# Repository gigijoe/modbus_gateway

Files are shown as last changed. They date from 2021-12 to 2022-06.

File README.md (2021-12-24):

## ESP32 Modbus TCP / RTU / ASCII Gateway

#### Hardware
ESP32 TTGO T8V1.7 16MB FLASH / 8MB PSRAM

Hardware

#### Feature
1.Combine Modbus TCP slave and Modbus RTU / ASCII master to act as Modbus TCP / RTU / ASCII Gateway\
2.Supports maximum 8 Modbus TCP connections synchronously. Listen on port 503\
3.Supports Modbus TCP slave of 8 digital input and 8 digital output locally. Listen on port 502\
4.Supports Wifi Access Point / Station / Ethernet network\
5.Supports mDNS service for zero IP configuration\
6.Supports DS1307 hardware RTC\
7.Supports NTP client\
8.Supports 1 port DS18B20 temperature sensor\
9.Supports 1 port ADC voltage reading\
10.Supports 20 x 4 dot matric LCD\

#### Reference

https://github.com/maxx-ukoo/esp32-modbus-tcp2rtu

https://github.com/iot-lorawan/esp32-ota-ble

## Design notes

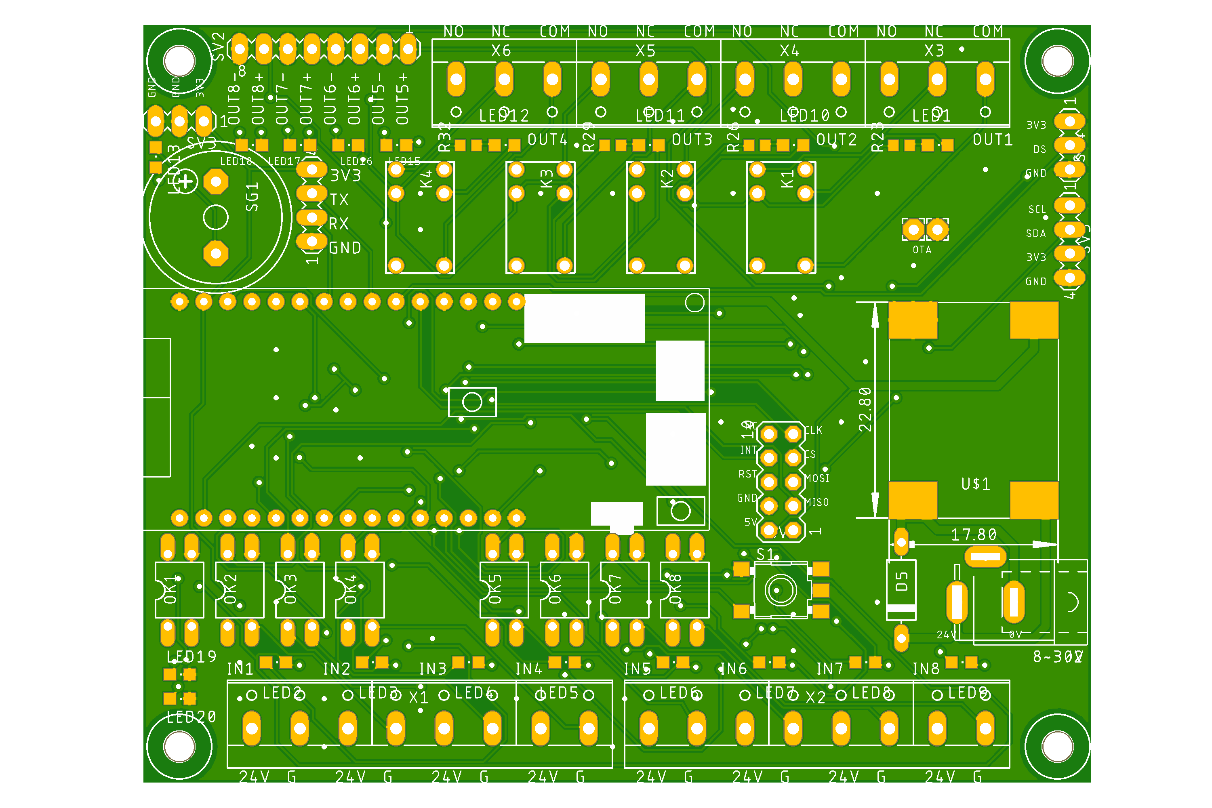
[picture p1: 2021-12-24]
hardware/7.x/top.png

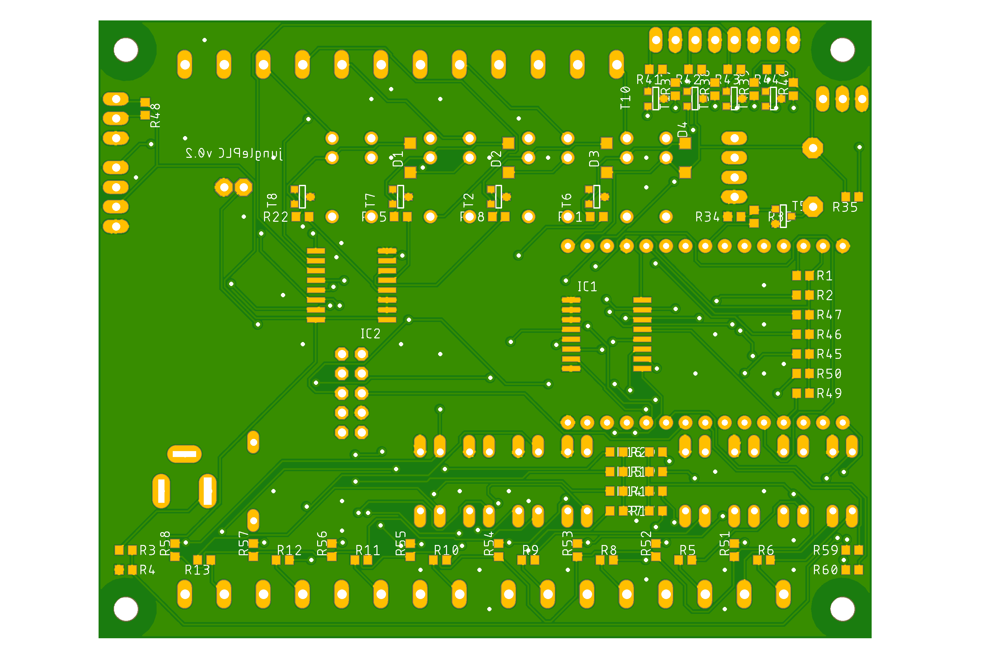
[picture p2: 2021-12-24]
hardware/7.x/bottom.png

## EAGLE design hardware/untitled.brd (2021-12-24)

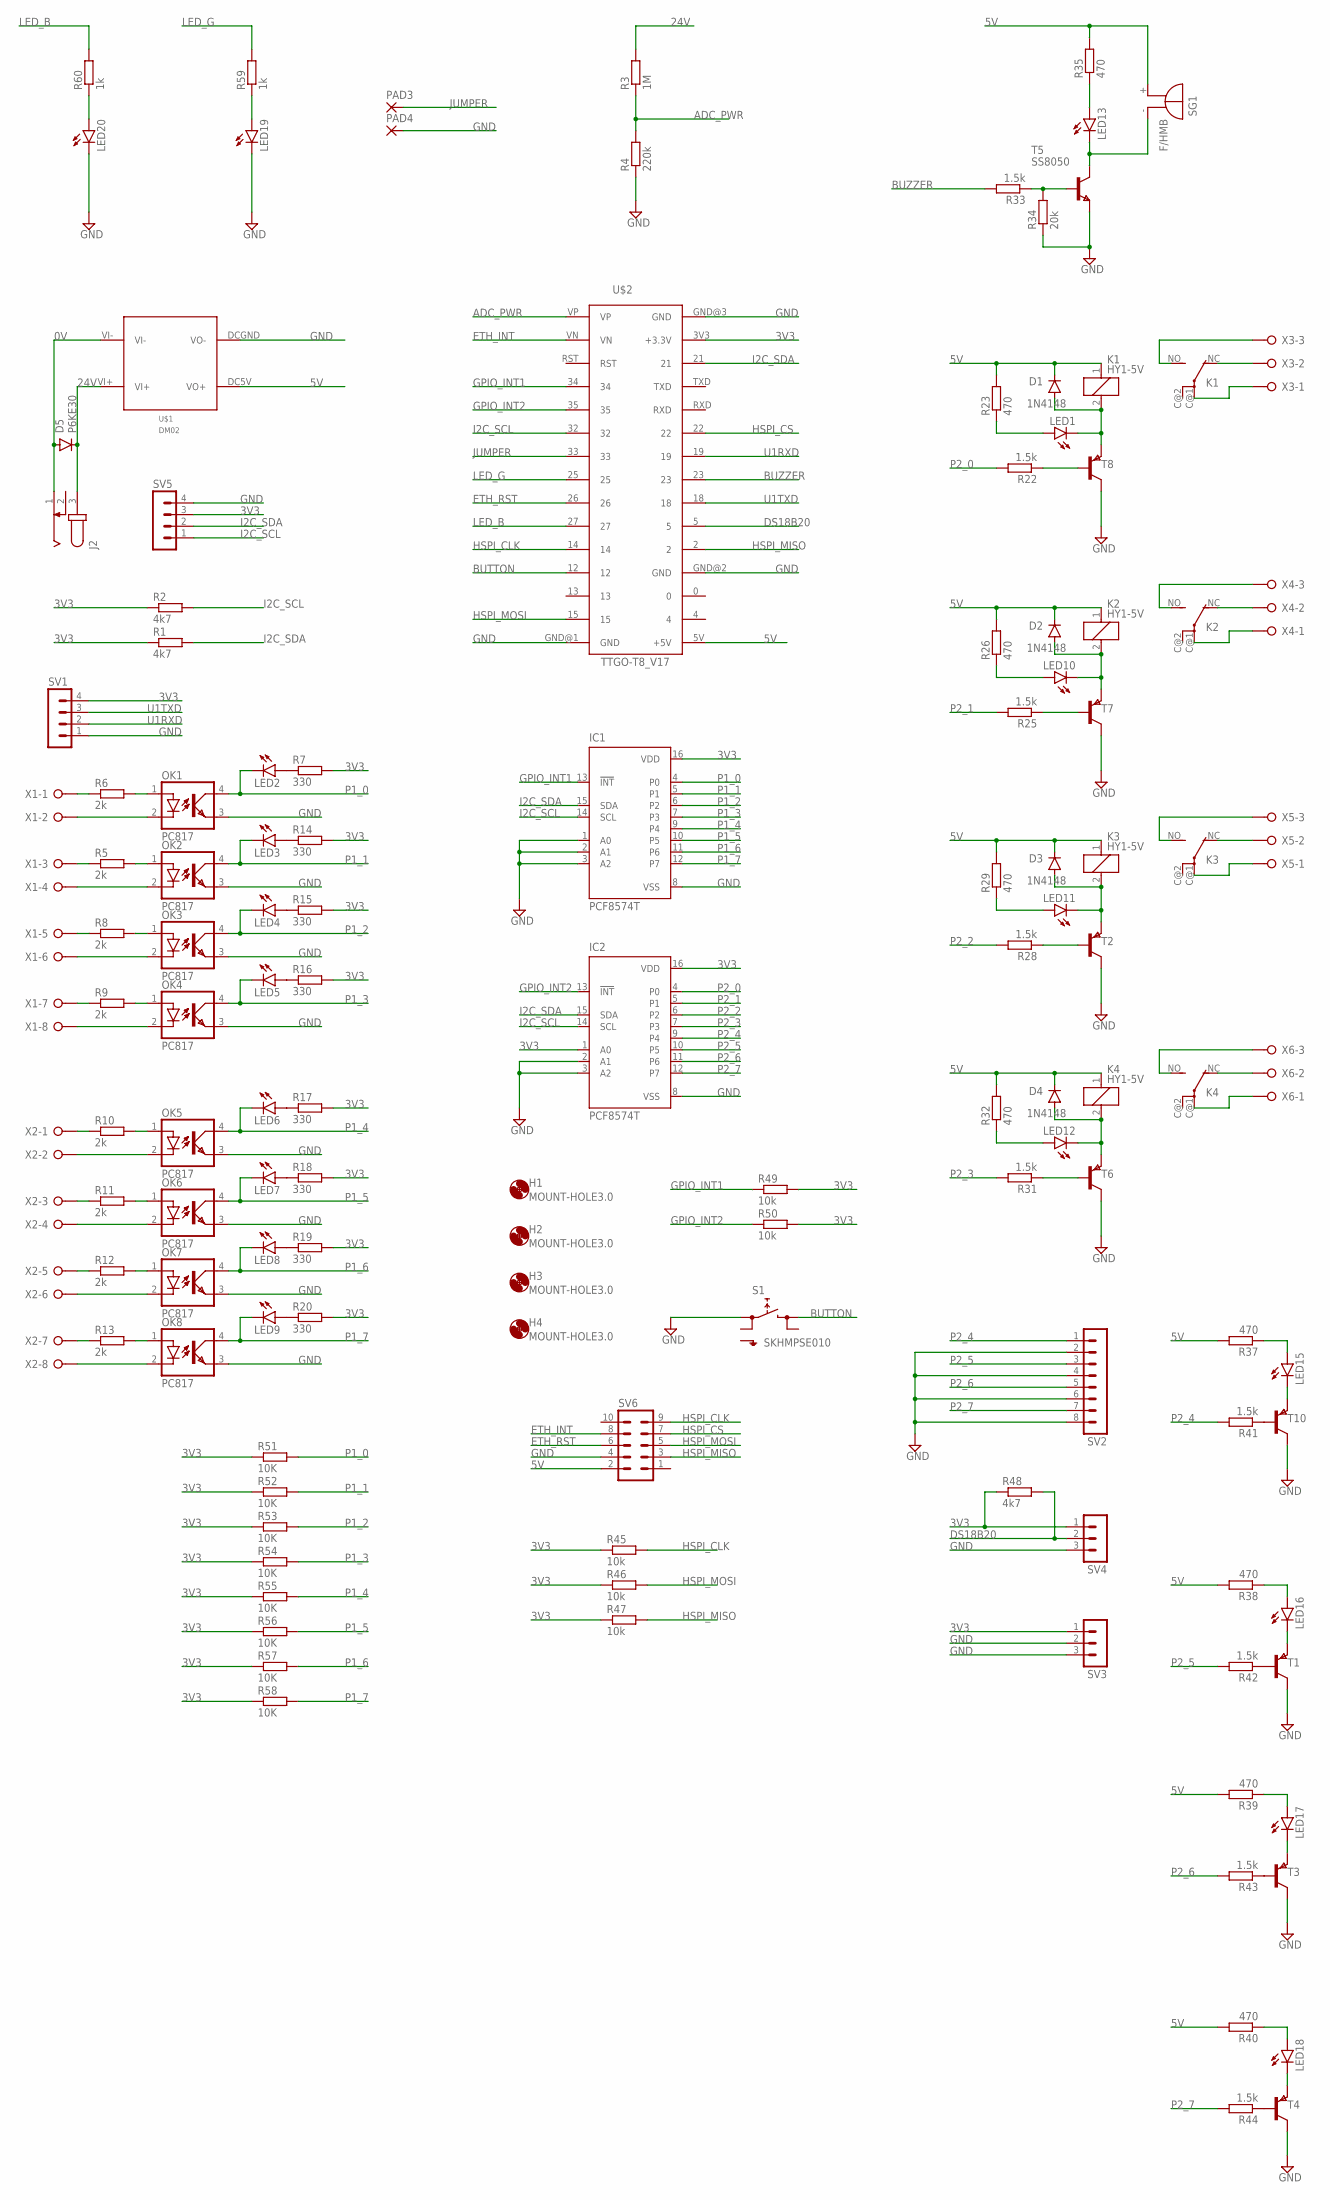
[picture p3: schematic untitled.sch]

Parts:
D1, D2, D3, D4: 1N4148; SOD123
D5: P6KE30; D-10
H1, H2, H3, H4: MOUNT-HOLE3.0; 3,0
IC1, IC2: PCF8574T; SO16W
J2: JACK-PLUG0; SPC4077
K1, K2, K3, K4: HY1-5V; HY
LED1, LED2, LED3, LED4, LED5, LED6, LED7, LED8, LED9, LED10, LED11, LED12, LED13, LED15, LED16, LED17, LED18, LED19, LED20: LEDCHIPLED_0805; CHIPLED_0805
OK1, OK2, OK3, OK4, OK5, OK6, OK7, OK8: PC817; DIL04
PAD3, PAD4: 2,15/1,0
R1, R2, R48: 4k7; R0603
R3: 1M; R0603
R4: 220k; R0603
R5, R6, R8, R9, R10, R11, R12, R13: 2k; R0603
R7, R14, R15, R16, R17, R18, R19, R20: 330; R0603
R22, R25, R28, R31, R33, R41, R42, R43, R44: 1.5k; R0603
R23, R26, R29, R32, R35, R37, R38, R39, R40: 470; R0603
R34: 20k; R0603
R45, R46, R47, R49, R50: 10k; R0603
R51, R52, R53, R54, R55, R56, R57, R58: 10K; R0603
R59, R60: 1k; R0603
S1: SKHMPSE010; SKHMPXE010
SG1: F/HMB
SV1, SV5: MA04-1
SV2: MA08-1
SV3, SV4: MA03-1
SV6: MA05-2
T1, T2, T3, T4, T6, T7, T8, T10: PNPSOT23; SOT-23
T5: SS8050; SOT-23
U$1: DM02
U$2: TTGO-T8_V17
X1, X2: W237-08P; W237-8P
X3, X4, X5, X6: W237-03P; W237-133

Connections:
0V: D5.A, J2.1, U$1.VI-
3V3: IC1.16 (VDD), IC2.1 (A0), IC2.16 (VDD), R1.1, R2.1, R7.2, R14.2, R15.2, R16.2, R17.2, R18.2, R19.2, R20.2, R45.1, R46.1, R47.1, R48.1, R49.2, R50.2, R51.1, R52.1, R53.1, R54.1, R55.1, R56.1, R57.1, R58.1, SV1.4, SV3.1, SV4.1, SV5.3, U$2.3V3 (+3.3V)
5V: D1.C, D2.C, D3.C, D4.C, K1.1, K2.1, K3.1, K4.1, R23.2, R26.2, R29.2, R32.2, R35.2, R37.2, R38.2, R39.2, R40.2, SG1.+, SV6.2, U$1.DC5V (VO+), U$2.5V (+5V)
24V: D5.C, J2.3, R3.2, U$1.VI+
ADC_PWR: R3.1, R4.2, U$2.VP
BUTTON: S1.3 (2.1), U$2.12
BUZZER: R33.2, U$2.23
DS18B20: R48.2, SV4.2, U$2.5
ETH_INT: SV6.8, U$2.VN
ETH_RST: SV6.6, U$2.26
GND: IC1.1 (A0), IC1.2 (A1), IC1.3 (A2), IC1.8 (VSS), IC2.2 (A1), IC2.3 (A2), IC2.8 (VSS), LED19.C, LED20.C, OK1.3 (EMIT), OK2.3 (EMIT), OK3.3 (EMIT), OK4.3 (EMIT), OK5.3 (EMIT), OK6.3 (EMIT), OK7.3 (EMIT), OK8.3 (EMIT), PAD4.1, R4.1, R34.1, S1.1 (1.1), SV1.1, SV2.2, SV2.4, SV2.6, SV2.8, SV3.2, SV3.3, SV4.3, SV5.4, SV6.4, T1.1 (C), T2.1 (C), T3.1 (C), T4.1 (C), T5.2 (E), T6.1 (C), T7.1 (C), T8.1 (C), T10.1 (C), U$1.DCGND (VO-), U$2.GND@1 (GND), U$2.GND@2 (GND), U$2.GND@3 (GND)
GPIO_INT1: IC1.13 (!INT), R49.1, U$2.34
GPIO_INT2: IC2.13 (!INT), R50.1, U$2.35
HSPI_CLK: R45.2, SV6.9, U$2.14
HSPI_CS: SV6.7, U$2.22
HSPI_MISO: R47.2, SV6.3, U$2.2
HSPI_MOSI: R46.2, SV6.5, U$2.15
I2C_SCL: IC1.14 (SCL), IC2.14 (SCL), R2.2, SV5.1, U$2.32
I2C_SDA: IC1.15 (SDA), IC2.15 (SDA), R1.2, SV5.2, U$2.21
JUMPER: PAD3.1, U$2.33
LED_B: R60.2, U$2.27
LED_G: R59.2, U$2.25
unnamed: R5.1, X1.3
unnamed: R6.1, X1.1
unnamed: OK1.1 (A), R6.2
unnamed: OK1.2 (C), X1.2
unnamed: OK2.1 (A), R5.2
unnamed: OK2.2 (C), X1.4
unnamed: R8.1, X1.5
unnamed: OK3.1 (A), R8.2
unnamed: OK3.2 (C), X1.6
unnamed: R9.1, X1.7
unnamed: OK4.1 (A), R9.2
unnamed: OK4.2 (C), X1.8
unnamed: R10.1, X2.1
unnamed: OK5.1 (A), R10.2
unnamed: OK5.2 (C), X2.2
unnamed: R11.1, X2.3
unnamed: OK6.1 (A), R11.2
unnamed: OK6.2 (C), X2.4
unnamed: R12.1, X2.5
unnamed: OK7.1 (A), R12.2
unnamed: OK7.2 (C), X2.6
unnamed: R13.1, X2.7
unnamed: OK8.1 (A), R13.2
unnamed: OK8.2 (C), X2.8
unnamed: R25.1, T7.3 (B)
unnamed: LED1.A, R23.1
unnamed: D2.A, K2.2, LED10.C, T7.2 (E)
unnamed: LED2.A, R7.1
unnamed: LED3.A, R14.1
unnamed: LED4.A, R15.1
unnamed: LED15.A, R37.1
unnamed: LED16.C, T1.2 (E)
unnamed: LED5.A, R16.1
unnamed: LED19.A, R59.1
unnamed: R22.1, T8.3 (B)
unnamed: D1.A, K1.2, LED1.C, T8.2 (E)
unnamed: K1.NO (S), X3.3
unnamed: K1.NC (O), X3.2
unnamed: R28.1, T2.3 (B)
unnamed: D3.A, K3.2, LED11.C, T2.2 (E)
unnamed: LED10.A, R26.1
unnamed: LED11.A, R29.1
unnamed: R31.1, T6.3 (B)
unnamed: D4.A, K4.2, LED12.C, T6.2 (E)
unnamed: LED12.A, R32.1
unnamed: K1.C@1, X3.1
unnamed: K2.NO (S), X4.3
unnamed: K2.NC (O), X4.2
unnamed: K2.C@1, X4.1
unnamed: K3.NO (S), X5.3
unnamed: K3.NC (O), X5.2
unnamed: K3.C@1, X5.1
unnamed: K4.NO (S), X6.3
unnamed: K4.NC (O), X6.2
unnamed: K4.C@1, X6.1
unnamed: LED15.C, T10.2 (E)
unnamed: LED20.A, R60.1
unnamed: R33.1, R34.2, T5.3 (B)
unnamed: R41.1, T10.3 (B)
unnamed: LED13.A, R35.1
unnamed: LED13.C, SG1.-, T5.1 (C)
unnamed: LED9.A, R20.1
unnamed: LED16.A, R38.1
unnamed: LED17.C, T3.2 (E)
unnamed: LED17.A, R39.1
unnamed: LED18.C, T4.2 (E)
unnamed: LED18.A, R40.1
unnamed: R42.1, T1.3 (B)
unnamed: R43.1, T3.3 (B)
unnamed: R44.1, T4.3 (B)
unnamed: LED8.A, R19.1
unnamed: LED7.A, R18.1
unnamed: LED6.A, R17.1
P1_0: IC1.4 (P0), LED2.C, OK1.4 (COL), R51.2
P1_1: IC1.5 (P1), LED3.C, OK2.4 (COL), R52.2
P1_2: IC1.6 (P2), LED4.C, OK3.4 (COL), R53.2
P1_3: IC1.7 (P3), LED5.C, OK4.4 (COL), R54.2
P1_4: IC1.9 (P4), LED6.C, OK5.4 (COL), R55.2
P1_5: IC1.10 (P5), LED7.C, OK6.4 (COL), R56.2
P1_6: IC1.11 (P6), LED8.C, OK7.4 (COL), R57.2
P1_7: IC1.12 (P7), LED9.C, OK8.4 (COL), R58.2
P2_0: IC2.4 (P0), R22.2
P2_1: IC2.5 (P1), R25.2
P2_2: IC2.6 (P2), R28.2
P2_3: IC2.7 (P3), R31.2
P2_4: IC2.9 (P4), R41.2, SV2.1
P2_5: IC2.10 (P5), R42.2, SV2.3
P2_6: IC2.11 (P6), R43.2, SV2.5
P2_7: IC2.12 (P7), R44.2, SV2.7
U1RXD: SV1.2, U$2.19
U1TXD: SV1.3, U$2.18

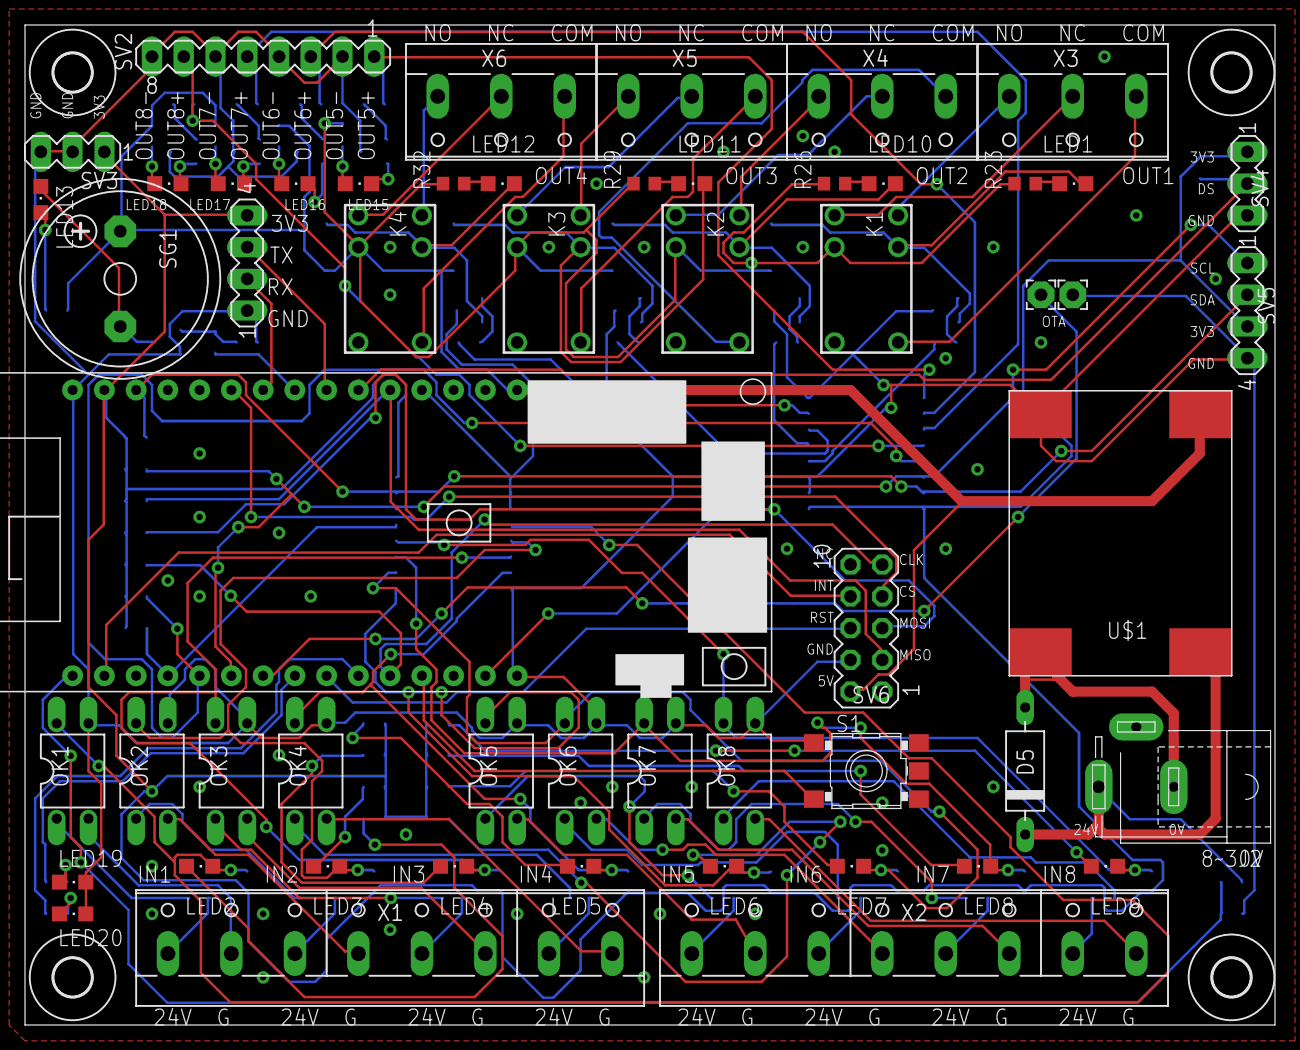
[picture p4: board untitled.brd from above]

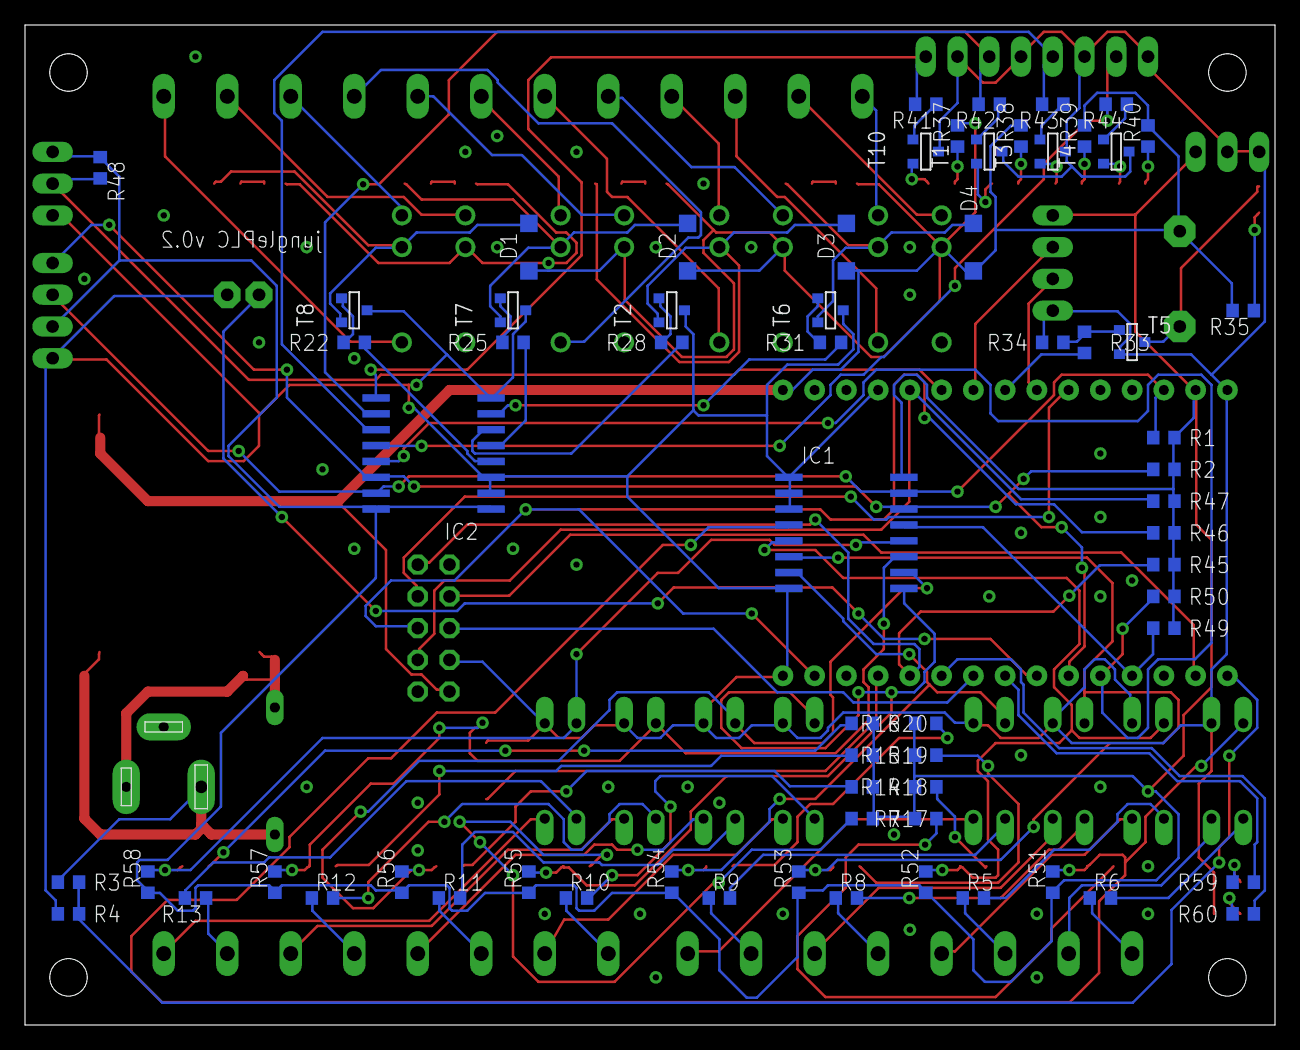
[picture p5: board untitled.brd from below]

Board: 2 copper layers, 100.0 x 80.0 mm, 125 parts (66 on the bottom side), 113 nets.

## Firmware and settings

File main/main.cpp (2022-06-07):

/* FreeModbus Slave Example ESP32

   Unless required by applicable law or agreed to in writing, this
   software is distributed on an "AS IS" BASIS, WITHOUT WARRANTIES OR
   CONDITIONS OF ANY KIND, either express or implied.
*/
#include <stdio.h>
#include "esp_err.h"
#include "sdkconfig.h"
#include "esp_log.h"
#include "esp_check.h"
#include "esp_system.h"
#include "esp_wifi.h"
#include "esp_event.h"
#include "esp_sntp.h"
#include "esp_mac.h"
#include "esp_chip_info.h"
#include "nvs_flash.h"

#include "mdns.h"
#include "esp_netif.h"

#include "driver/gpio.h"
#include "esp32/rom/gpio.h"
#include "driver/i2c.h"
#include "soc/rtc_io_reg.h"

#include "driver/adc.h"
#include "esp_adc_cal.h"

#include "network.h"
#include "telnetd.h"
#include "icmp_echo.h"

#include "esp_vfs.h"
#include "esp_vfs_dev.h"
#include "esp_console.h"
#include "driver/uart.h"
#include "linenoise/linenoise.h"
#include "argtable3/argtable3.h"

#include "led.h"
#include "i2cdev.h"
#include "ds1307.h"
#include "ds3231.h"
#include "ds18b20.h"
#include "pcf8574.hpp"
#include "lcd204-i2c.hpp"
//#include "sdmmc.h"

#include "modbus_tcp_slave.h"
#include "modbus_tcp2serial.h"
#include "modbus_data.h"

#include <lwip/dns.h>

#include <lwip/err.h>
#include <lwip/sockets.h>
#include <lwip/sys.h>
#include <lwip/netdb.h>
#include <lwip/err.h>

#include "ota_ble.h"
#include "ota_https.h"

#include "http_server.h"

#define TAG "Main"

static nvs_handle my_nvs_handle;

#define HOSTNAME_MAX_LEN 32
#define DESCRIPTION_MAX_LEN 64

typedef struct {
    char hostname[HOSTNAME_MAX_LEN];
    char description[DESCRIPTION_MAX_LEN];
#if CONFIG_EXAMPLE_CONNECT_ETHERNET
    bool enable_eth;
#endif
    bool enable_ntp;
    bool enable_mdns;
    bool enable_telnetd;
    bool enable_modbus_tcp2serial;
} sys_cfg_t;

static sys_cfg_t s_sys_cfg = {}; 

// https://blog.csdn.net/libin55/article/details/108206159

#define SYSLOG_QUEUE_SIZE   4096
#define SIZEOF_SYSLOG       sizeof(syslog_t)

/* The variable used to hold the queue's data structure. */
static StaticQueue_t xStaticQueue;
//EXT_RAM_ATTR uint8_t ucQueueStorageArea[ SYSLOG_QUEUE_SIZE * SIZEOF_SYSLOG ];
EXT_RAM_BSS_ATTR uint8_t ucQueueStorageArea[ SYSLOG_QUEUE_SIZE * SIZEOF_SYSLOG ];

static QueueHandle_t s_syslog_queue;

#define CMD_SYS_CFG  "sys_cfg"

void system_load_config()
{
    esp_err_t err = nvs_open("storage", NVS_READWRITE, &my_nvs_handle);
    if(err != ESP_OK) {
        ESP_LOGE(TAG, "Error (%d) opening NVS!\n", err);
        return;
    }

    size_t l = sizeof(sys_cfg_t);
    err = nvs_get_blob(my_nvs_handle, CMD_SYS_CFG, &s_sys_cfg, &l);
    if(err != ESP_OK) {
        ESP_LOGI(TAG, "No system config cached ...");
    }    

    nvs_close(my_nvs_handle);
}

void system_save_config()
{
    esp_err_t err = nvs_open("storage", NVS_READWRITE, &my_nvs_handle);
    if(err != ESP_OK) {
        ESP_LOGE(TAG, "Error (%d) opening NVS!\n", err);
        return;
    }

    err = nvs_set_blob(my_nvs_handle, CMD_SYS_CFG, &s_sys_cfg, sizeof(s_sys_cfg));
    if(err != ESP_OK)
        ESP_LOGE(TAG, "Fail save system config !!!");

    nvs_commit(my_nvs_handle);
    nvs_close(my_nvs_handle);
}

void system_factory_reset()
{
    esp_err_t err = nvs_open("storage", NVS_READWRITE, &my_nvs_handle);

    if(err != ESP_OK) {
        ESP_LOGE(TAG, "Error (%d) opening NVS!\n", err);
        return;
    }

    nvs_erase_key(my_nvs_handle, CMD_SYS_CFG);

    nvs_commit(my_nvs_handle);
    nvs_close(my_nvs_handle);
}

/*
*
*/

#if CONFIG_MB_MDNS_IP_RESOLVER

#define MB_MDNS_PORT            (CONFIG_FMB_TCP_PORT_DEFAULT)

#if CONFIG_FMB_CONTROLLER_SLAVE_ID_SUPPORT
#define MB_DEVICE_ID (uint32_t)CONFIG_FMB_CONTROLLER_SLAVE_ID
#endif

// convert mac from binary format to string
static inline char* gen_mac_str(const uint8_t* mac, const char* pref, char* mac_str)
{
    sprintf(mac_str, "%s%02X%02X%02X%02X%02X%02X", pref, MAC2STR(mac));
    return mac_str;
}

static void start_mdns_service(void)
{
    char temp_str[32] = {0};
    uint8_t sta_mac[6] = {0};
    ESP_ERROR_CHECK(esp_read_mac(sta_mac, ESP_MAC_WIFI_STA));
    const char *hostname = s_sys_cfg.hostname;
    //initialize mDNS
    ESP_ERROR_CHECK(mdns_init());
    //set mDNS hostname (required if you want to advertise services)
    ESP_ERROR_CHECK(mdns_hostname_set(hostname));
    ESP_LOGI(TAG, "mdns hostname set to: [%s]", hostname);

    //set default mDNS instance name
    ESP_ERROR_CHECK(mdns_instance_name_set(hostname));

    //structure with TXT records
    mdns_txt_item_t serviceTxtData[] = {
        {"board","modbus_gateway"} // board=modbus_gateway
    };

    //initialize service
    ESP_ERROR_CHECK(mdns_service_add(hostname, "_modbus", "_tcp", MB_MDNS_PORT, serviceTxtData, 1));
    //add mac key string text item
    ESP_ERROR_CHECK(mdns_service_txt_item_set("_modbus", "_tcp", "mac", gen_mac_str(sta_mac, "\0", temp_str)));
}

static void stop_mdns_service(void)
{
    mdns_free();
}

#endif // CONFIG_MB_MDNS_IP_RESOLVER

static void initialize_gpio12()
{
    gpio_config_t io_conf;
    //disable interrupt
    io_conf.intr_type = static_cast<gpio_int_type_t>(GPIO_PIN_INTR_DISABLE);
    //set as output mode
    io_conf.mode = GPIO_MODE_INPUT;
    //bit mask of the pins that you want to set,e.g.GPIO18/19
    io_conf.pin_bit_mask = (BIT(12)); //GPIO_SEL_12;
    //disable pull-down mode
    io_conf.pull_down_en = GPIO_PULLDOWN_DISABLE;
    //disable pull-up mode
    io_conf.pull_up_en = GPIO_PULLUP_ENABLE;
    //configure GPIO with the given settings
    gpio_config(&io_conf);

    gpio_set_direction(GPIO_NUM_12, GPIO_MODE_INPUT);
}

static esp_err_t initialize_system(void)
{
    initialize_gpio12();

    esp_err_t result = nvs_flash_init();
    if (result == ESP_ERR_NVS_NO_FREE_PAGES || result == ESP_ERR_NVS_NEW_VERSION_FOUND) {
      ESP_ERROR_CHECK(nvs_flash_erase());
      result = nvs_flash_init();
    }
    ESP_RETURN_ON_FALSE((result == ESP_OK), ESP_ERR_INVALID_STATE,
                            TAG,
                            "nvs_flash_init fail, returns(0x%x).",
                            (uint32_t)result);
    result = esp_netif_init();
    ESP_RETURN_ON_FALSE((result == ESP_OK), ESP_ERR_INVALID_STATE,
                            TAG,
                            "esp_netif_init fail, returns(0x%x).",
                            (uint32_t)result);
    result = esp_event_loop_create_default();
    ESP_RETURN_ON_FALSE((result == ESP_OK), ESP_ERR_INVALID_STATE,
                            TAG,
                            "esp_event_loop_create_default fail, returns(0x%x).",
                            (uint32_t)result);

    snprintf(s_sys_cfg.hostname, HOSTNAME_MAX_LEN, "modbus_gateway");
    snprintf(s_sys_cfg.description, DESCRIPTION_MAX_LEN, "unknown");
#if CONFIG_EXAMPLE_CONNECT_ETHERNET
    s_sys_cfg.enable_eth = false;
#endif
    s_sys_cfg.enable_ntp = true;
    s_sys_cfg.enable_mdns = true;
    s_sys_cfg.enable_telnetd = false;
    s_sys_cfg.enable_modbus_tcp2serial = true;

    system_load_config();
    wifi_load_config();
    eth_load_config();

    /* Create a queue capable of containing 10 uint64_t values. */
    s_syslog_queue = xQueueCreateStatic( SYSLOG_QUEUE_SIZE,
                                 SIZEOF_SYSLOG,
                                 ucQueueStorageArea,
                                 &xStaticQueue );

#if CONFIG_MB_MDNS_IP_RESOLVER
    // Start mdns service and register device
    if(s_sys_cfg.enable_mdns)
        start_mdns_service();
#endif
#if CONFIG_EXAMPLE_CONNECT_ETHERNET
    if(s_sys_cfg.enable_eth)
        network_initialize(NETWORK_TYPE_ETH, false);
    else
#endif
        network_initialize(NETWORK_TYPE_WIFI, gpio_get_level(GPIO_NUM_12) == 0); /* if button released than enable blufi */

ESP_LOGI(TAG, "Button level is %d", gpio_get_level(GPIO_NUM_12));

    // This helper function configures Wi-Fi or Ethernet, as selected in menuconfig.
    // Read "Establishing Wi-Fi or Ethernet Connection" section in
    // examples/protocols/README.md for more information about this function.
    result = network_start();

    return ESP_OK;
}

static esp_err_t deinitialize_system(void)
{
    esp_err_t err = ESP_OK;

    err = network_stop();
    ESP_RETURN_ON_FALSE((err == ESP_OK), ESP_ERR_INVALID_STATE,
                                   TAG,
                                   "network_disconnect fail, returns(0x%x).",
                                   (uint32_t)err);
    network_deinitialize();
    err = esp_event_loop_delete_default();
    ESP_RETURN_ON_FALSE((err == ESP_OK), ESP_ERR_INVALID_STATE,
                                       TAG,
                                       "esp_event_loop_delete_default fail, returns(0x%x).",
                                       (uint32_t)err);
    err = esp_netif_deinit();
    ESP_RETURN_ON_FALSE((err == ESP_OK || err == ESP_ERR_NOT_SUPPORTED), ESP_ERR_INVALID_STATE,
                                        TAG,
                                        "esp_netif_deinit fail, returns(0x%x).",
                                        (uint32_t)err);
    err = nvs_flash_deinit();
    ESP_RETURN_ON_FALSE((err == ESP_OK), ESP_ERR_INVALID_STATE,
                                TAG,
                                "nvs_flash_deinit fail, returns(0x%x).",
                                (uint32_t)err);
#if CONFIG_MB_MDNS_IP_RESOLVER
    stop_mdns_service();
#endif
    return err;
}

/*
*
*/

static int restart(int argc, char** argv)
{
    esp_restart();
}

static void register_restart()
{
    const esp_console_cmd_t cmd = {
        .command = "restart",
        .help = "Restart",
        .hint = NULL,
        .func = &restart,
        .argtable = NULL,
    };
    ESP_ERROR_CHECK( esp_console_cmd_register(&cmd) );
}

static uint8_t atohex(char *s)
{
  uint8_t value = 0;
  if(!s)
    return 0;

  if(*s >= '0' && *s <= '9')
    value = (*s - '0') << 4;
  else if(*s >= 'A' && *s <= 'F')
    value = ((*s - 'A') + 10) << 4;
  else if(*s >= 'a' && *s <= 'f')
    value = ((*s - 'a') + 10) << 4;

  s++;

  if(*s >= '0' && *s <= '9')
    value |= (*s - '0');
  else if(*s >= 'A' && *s <= 'F')
    value |= ((*s - 'A') + 10);
  else if(*s >= 'a' && *s <= 'f')
    value |= ((*s - 'a') + 10);

  return value;
}

static int wifi(int argc, char** argv)
{
    esp_ip4_addr_t ip4_addr;
    char buf[16];

    if(argc <= 1) {
        printf("Wifi SSID : %s\n", wifi_get_ssid());
        printf("Wifi Password : %s\n", wifi_get_password());
        uint8_t *b = wifi_get_bssid();
        printf("Wifi BSSID :  %02x:%02x:%02x:%02x:%02x:%02x\n", b[0], b[1], b[2], b[3], b[4], b[5]);
        printf("Wifi Channel : %u\n", wifi_get_channel());
        uint8_t mac[6] = {0};
        //esp_read_mac(mac, ESP_MAC_WIFI_STA);
        esp_wifi_get_mac(WIFI_IF_STA, mac);
        printf("Wifi STA MAC - %02x:%02x:%02x:%02x:%02x:%02x\n", mac[0], mac[1], mac[2], mac[3], mac[4], mac[5]);
        printf("Status : ");
        switch(wifi_get_status()) {
            case WIFI_STOPPED: printf("Stopped ...\n");
                break;
            case WIFI_STARTED: printf("Started ...\n");
                break;
            case WIFI_DISCONNECTED: printf("Disconnected ...\n");
                break;
            case WIFI_CONNECTING: printf("Connecting ...\n");
                break;
            case WIFI_CONNECTED: printf("Connected ...\n");
                ip4_addr = wifi_get_static_ip();
                if(ip4_addr.addr == 0) { /* 0.0.0.0 */
                    esp_netif_t *netif = get_network_netif_from_desc("sta");
                    esp_netif_ip_info_t ip_info;
                    esp_netif_get_ip_info(netif, &ip_info);
                    printf("DHCP IP : " IPSTR "\n", IP2STR(&ip_info.ip));
                    printf("Gateway : " IPSTR "\n", IP2STR(&ip_info.gw));
                } else {
                    printf("Static IP : %s\n", esp_ip4addr_ntoa(&ip4_addr, buf, 16));
                    ip4_addr = wifi_get_static_gateway();
                    printf("Gateway : %s\n", esp_ip4addr_ntoa(&ip4_addr, buf, 16));
                }
                break;
            case WIFI_CONNECT_FAIL: printf("Connect fail ...\n");
                break;
            case WIFI_INTERNAL_ERROR: printf("Internal error ...\n");
                 break;
        }
#ifdef CONFIG_EXAMPLE_ENABLE_WIFI_AP
        printf("Wifi AP SSID : %s\n", wifi_get_ap_ssid());
        printf("Wifi AP Password : %s\n", wifi_get_ap_password());
        printf("Wifi AP Channel : %u\n", wifi_get_ap_channel());
        //ESP_ERROR_CHECK(esp_read_mac(mac, ESP_MAC_WIFI_SOFTAP));
        //ESP_ERROR_CHECK(esp_wifi_get_mac(WIFI_IF_AP, mac));
        //printf("Wifi AP MAC - %02x:%02x:%02x:%02x:%02x:%02x\n", mac[0], mac[1], mac[2], mac[3], mac[4], mac[5]);
        uint8_t *m = wifi_get_ap_mac();
        printf("Wifi AP MAC :  %02x:%02x:%02x:%02x:%02x:%02x\n", m[0], m[1], m[2], m[3], m[4], m[5]);

        esp_netif_t *netif = get_network_netif_from_desc("ap");
        esp_netif_ip_info_t ip_info;
        esp_netif_get_ip_info(netif, &ip_info);
        printf("IP : " IPSTR "\n", IP2STR(&ip_info.ip));
#endif
        return 0;
    }

    if(strcasecmp(argv[1], "ssid") == 0) {
        if(argc >= 3)
            wifi_set_ssid(argv[2]);
        else
            printf("Wifi SSID : %s\n", wifi_get_ssid());
    } else if(strcasecmp(argv[1], "password") == 0) {
        if(argc >= 3)
            wifi_set_password(argv[2]);
        else
            printf("Wifi Password : %s\n", wifi_get_password());
    } else if(strcasecmp(argv[1], "bssid") == 0) {
        if(argc >= 3) {
            uint8_t i = 0;
            uint8_t mac[6] = {0};
            char *s = strdup(argv[2]);
            char *t = strtok(s, ":");
            while(t != NULL && i < 6) {
                mac[i++] = atohex(t);
                t = strtok(NULL, ":");
            }
            wifi_set_bssid(mac);
        } else {
            uint8_t *mac = wifi_get_bssid();
            printf("Wifi BSSID :  %02x:%02x:%02x:%02x:%02x:%02x\n", mac[0], mac[1], mac[2], mac[3], mac[4], mac[5]);
        }
    } else if(strcasecmp(argv[1], "channel") == 0) {
        if(argc >= 3) {
            int v = atoi(argv[2]);
            if(v >= 0 && v <= 13)
                wifi_set_channel((uint8_t)(v & 0xff));
            else
                printf("Wifi Channel range from 0 to 13\n");
        } else
            printf("Wifi Channel : %u\n", wifi_get_ap_channel());
    } else if(strcasecmp(argv[1], "ap_mac") == 0) {
        if(argc >= 3) {
            uint8_t i = 0;
            uint8_t mac[6] = {0};
            char *s = strdup(argv[2]);
            char *t = strtok(s, ":");
            while(t != NULL && i < 6) {
                mac[i++] = atohex(t);
                t = strtok(NULL, ":");
            }
            wifi_set_ap_mac(mac);
        } else {
            uint8_t *mac = wifi_get_ap_mac();
            printf("Wifi AP MAC :  %02x:%02x:%02x:%02x:%02x:%02x\n", mac[0], mac[1], mac[2], mac[3], mac[4], mac[5]);
        }
    } else if(strcasecmp(argv[1], "ap_ssid") == 0) {
        if(argc >= 3)
            wifi_set_ap_ssid(argv[2]);
        else
            printf("Wifi AP SSID : %s\n", wifi_get_ap_ssid());
    } else if(strcasecmp(argv[1], "ap_password") == 0) {
        if(argc >= 3)
            wifi_set_ap_password(argv[2]);
        else
            printf("Wifi AP Password : %s\n", wifi_get_ap_password());
    } else if(strcasecmp(argv[1], "ap_channel") == 0) {
        if(argc >= 3) {
            int v = atoi(argv[2]);
            if(v >= 0 && v <= 13)
                wifi_set_ap_channel((uint8_t)(v & 0xff));
            else
                printf("Wifi AP Channel range from 0 to 13\n");
        } else
            printf("Wifi AP Channel : %u\n", wifi_get_ap_channel());
    } else if(strcasecmp(argv[1], "start") == 0) {
        network_start();
    } else if(strcasecmp(argv[1], "stop") == 0) {
        network_stop();
    } else if(strcasecmp(argv[1], "staticip") == 0) {
        if(argc >= 3) {            
            esp_err_t r = esp_netif_str_to_ip4(argv[2], &ip4_addr);
            if(r == ESP_OK)
                wifi_set_static_ip(&ip4_addr);
            else
                printf("Invalid IP : %s\n", argv[2]);
        } else {
            ip4_addr = wifi_get_static_ip();
            printf("Wifi static IP : %s\n", esp_ip4addr_ntoa(&ip4_addr, buf, 16));
        }
    } else if(strcasecmp(argv[1], "gateway") == 0) {
        if(argc >= 3) {            
            esp_err_t r = esp_netif_str_to_ip4(argv[2], &ip4_addr);
            if(r == ESP_OK)
                wifi_set_static_gateway(&ip4_addr);
            else
                printf("Invalid Gateway : %s\n", argv[2]);
        } else {            
            ip4_addr = wifi_get_static_gateway();
            printf("Wifi Gateway : %s\n", esp_ip4addr_ntoa(&ip4_addr, buf, 16));
        }
    } else if(strcasecmp(argv[1], "netmask") == 0) {
        if(argc >= 3) {            
            esp_err_t r = esp_netif_str_to_ip4(argv[2], &ip4_addr);
            if(r == ESP_OK)
                wifi_set_static_netmask(&ip4_addr);
            else
                printf("Invalid Netmask : %s\n", argv[2]);
        } else {            
            ip4_addr = wifi_get_static_netmask();
            printf("Wifi Netmask : %s\n", esp_ip4addr_ntoa(&ip4_addr, buf, 16));
        }
    } else if(strcasecmp(argv[1], "save") == 0) {
        wifi_save_config();
        printf("Wifi config saved ...\n");
    } else if(strcasecmp(argv[1], "reset") == 0) {
        wifi_factory_reset();
        printf("Reset done ...\n");
    } else if(strcasecmp(argv[1], "reconnect") == 0) {
        wifi_reconnect();
        printf("Reconnect ...\n");
    } else
        printf("Unknown command !!!\n");

    return 0; 
}

static void register_wifi()
{
    const esp_console_cmd_t cmd = {
        .command = "wifi",
        .help = "wifi [ start | stop | ssid | password | bssid | channel | staticip | gateway | ap_mac | ap_ssid | ap_password | ap_channel | save | reset | reconnect ] <string>",
        .hint = NULL,
        .func = &wifi,
        .argtable = NULL,
    };
    ESP_ERROR_CHECK( esp_console_cmd_register(&cmd) );
}
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
extern "C" void app_main(void)
{
    ESP_ERROR_CHECK(initialize_system());

    // Set UART log level
    esp_log_level_set(TAG, ESP_LOG_INFO);

    xTaskCreatePinnedToCore(ledTask, "ledTask", 2048, NULL, 3, NULL, 0);

#if CONFIG_EXAMPLE_CONNECT_ETHERNET
    if(s_sys_cfg.enable_eth == false) {
#else
    {
#endif
        led_sos_beep(&s_buzzer);
        led_slow_flash(&s_led27);
    }
    
    //initialize_sdmmc();
    initialize_gpio_isr();
    xTaskCreatePinnedToCore(&adcTask, "adcTask", 3072, NULL, 4, NULL, 0);
    xTaskCreatePinnedToCore(&tempTask, "tempTask", 3072, NULL, 4, NULL, 0);

    initialize_i2c0(); /* Must before ds1307 RTC & pcf8574 gpio */
    xTaskCreatePinnedToCore(&rtcTimeTask, "rtcTimeTask", 3072, NULL, 4, NULL, 1);

    initialize_sntp();
    xTaskCreatePinnedToCore(&sntpTask, "sntpTask", 3072, NULL, 4, NULL, 0);

    initialize_ext_gpio();
    xTaskCreatePinnedToCore(&extGpioTask, "extGpioTask", 4096, NULL, 4, NULL, 1);

    xTaskCreatePinnedToCore(&mbTcpSlaveTask, "mbTcpSlaveTask", 8192, semWriteExtGpio, 5, NULL, 0);
    //xTaskCreatePinnedToCore(&mbRtuMasterTask, "mbRtuMasterTask", 8192, NULL, 5, NULL, 0);

    /* RS485 9600 8E1 */
    initialize_modbus_tcp2serial();
    xTaskCreatePinnedToCore(&mbTcp2Serial_task, "mbTcp2Serial_task", 3072, NULL, 4, NULL, 0);

    xTaskCreatePinnedToCore(&consoleTask, "consoleTask", 3072, NULL, 3, NULL, 1);
    xTaskCreatePinnedToCore(&telnetdTask, "telnetdTask", 4096, NULL, 2, NULL, 1);

    //xTaskCreatePinnedToCore(&appTask, "appTask", 4096, NULL, 3, NULL, 0);

#ifdef CONFIG_EXAMPLE_ENABLE_WIFI_AP
    start_webserver();
#endif

    while(1) {
#if 1        
#if CONFIG_EXAMPLE_CONNECT_ETHERNET
        if(s_sys_cfg.enable_eth == false) {
#else
        {
#endif
            wifi_ap_record_t ap_info;
            esp_err_t err = esp_wifi_sta_get_ap_info(&ap_info);
            if(err == ESP_OK) {
                //ESP_LOGI(TAG, "rssi : %d", ap_info.rssi);
                if(ap_info.rssi < -60)
                    led_slow_flash(&s_buzzer);
                else if(ap_info.rssi < -70)
                    led_normal_flash(&s_buzzer);
                else if(ap_info.rssi < -80)
                    led_fast_flash(&s_buzzer);
                else
                    led_off(&s_buzzer);
            } else
                led_sos_beep(&s_buzzer);
        }
#endif
        vTaskDelay(1000 / portTICK_PERIOD_MS);
    }

    ESP_ERROR_CHECK(deinitialize_system());
}

/*

avahi-browse -t _modbus._tcp -r

+   wlo1 IPv4 modbus_gateway                                     _modbus._tcp         local
=   wlo1 IPv4 modbus_gateway                                     _modbus._tcp         local
   hostname = [modbus_gateway.local]
   address = [192.168.31.147]
   port = [502]
   txt = ["board=modbus_gateway" "mac=AC67B22A886C"]
+   wlo1 IPv4 airCon01                                      _modbus._tcp         local
=   wlo1 IPv4 airCon01                                      _modbus._tcp         local
   hostname = [airCon01.local]
   address = [192.168.31.203]
   port = [502]
   txt = ["board=modbus_gateway" "mac=AC67B22A8440"]

*/

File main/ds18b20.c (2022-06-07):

/*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
    You should have received a copy of the GNU General Public License
     along with this program.  If not, see <http://www.gnu.org/licenses/>.
*/
#include "freertos/FreeRTOS.h"
#include "freertos/task.h"
#include "driver/gpio.h"
#include "esp_timer.h"
#include "esp32/rom/gpio.h"
#include "esp32/rom/ets_sys.h"
#include "ds18b20.h"

// OneWire commands
#define GETTEMP			0x44  // Tells device to take a temperature reading and put it on the scratchpad
#define SKIPROM			0xCC  // Command to address all devices on the bus
#define SELECTDEVICE	0x55  // Command to address all devices on the bus
#define COPYSCRATCH     0x48  // Copy scratchpad to EEPROM
#define READSCRATCH     0xBE  // Read from scratchpad
#define WRITESCRATCH    0x4E  // Write to scratchpad
#define RECALLSCRATCH   0xB8  // Recall from EEPROM to scratchpad
#define READPOWERSUPPLY 0xB4  // Determine if device needs parasite power
#define ALARMSEARCH     0xEC  // Query bus for devices with an alarm condition
// Scratchpad locations
#define TEMP_LSB        0
#define TEMP_MSB        1
#define HIGH_ALARM_TEMP 2
#define LOW_ALARM_TEMP  3
#define CONFIGURATION   4
#define INTERNAL_BYTE   5
#define COUNT_REMAIN    6
#define COUNT_PER_C     7
#define SCRATCHPAD_CRC  8
// DSROM FIELDS
#define DSROM_FAMILY    0
#define DSROM_CRC       7
// Device resolution
#define TEMP_9_BIT  0x1F //  9 bit
#define TEMP_10_BIT 0x3F // 10 bit
#define TEMP_11_BIT 0x5F // 11 bit
#define TEMP_12_BIT 0x7F // 12 bit

uint8_t DS_GPIO;
uint8_t init=0;
uint8_t bitResolution=12;
uint8_t devices=0;

DeviceAddress ROM_NO;
uint8_t LastDiscrepancy;
uint8_t LastFamilyDiscrepancy;
bool LastDeviceFlag;

/// Sends one bit to bus
void ds18b20_write(char bit){
	if (bit & 1) {
		gpio_set_direction(DS_GPIO, GPIO_MODE_OUTPUT);
		noInterrupts();
		gpio_set_level(DS_GPIO,0);
		ets_delay_us(6);
		gpio_set_direction(DS_GPIO, GPIO_MODE_INPUT);	// release bus
		ets_delay_us(64);
		interrupts();
	} else {
		gpio_set_direction(DS_GPIO, GPIO_MODE_OUTPUT);
		noInterrupts();
		gpio_set_level(DS_GPIO,0);
		ets_delay_us(60);
		gpio_set_direction(DS_GPIO, GPIO_MODE_INPUT);	// release bus
		ets_delay_us(10);
		interrupts();
	}
}

// Reads one bit from bus
unsigned char ds18b20_read(void){
	unsigned char value = 0;
	gpio_set_direction(DS_GPIO, GPIO_MODE_OUTPUT);
	noInterrupts();
	gpio_set_level(DS_GPIO, 0);
	ets_delay_us(6);
	gpio_set_direction(DS_GPIO, GPIO_MODE_INPUT);
	ets_delay_us(9);
	value = gpio_get_level(DS_GPIO);
	ets_delay_us(55);
	interrupts();
	return (value);
}
// Sends one byte to bus
void ds18b20_write_byte(char data){
  unsigned char i;
  unsigned char x;
  for(i=0;i<8;i++){
    x = data>>i;
    x &= 0x01;
    ds18b20_write(x);
  }
  ets_delay_us(100);
}
// Reads one byte from bus
unsigned char ds18b20_read_byte(void){
  unsigned char i;
  unsigned char data = 0;
  for (i=0;i<8;i++)
  {
    if(ds18b20_read()) data|=0x01<<i;
    ets_delay_us(15);
  }
  return(data);
}
// Sends reset pulse
unsigned char ds18b20_reset(void){
	unsigned char presence;
	gpio_set_direction(DS_GPIO, GPIO_MODE_OUTPUT);
	noInterrupts();
	gpio_set_level(DS_GPIO, 0);
	ets_delay_us(480);
	gpio_set_level(DS_GPIO, 1);
	gpio_set_direction(DS_GPIO, GPIO_MODE_INPUT);
	ets_delay_us(70);
	presence = (gpio_get_level(DS_GPIO) == 0);
	ets_delay_us(410);
	interrupts();
	return presence;
}

bool ds18b20_setResolution(const DeviceAddress tempSensorAddresses[], int numAddresses, uint8_t newResolution) {
	bool success = false;
	// handle the sensors with configuration register
	newResolution = constrain(newResolution, 9, 12);
	uint8_t newValue = 0;
	ScratchPad scratchPad;
	// loop through each address
	for (int i = 0; i < numAddresses; i++){
		// we can only update the sensor if it is connected
		if (ds18b20_isConnected((DeviceAddress*) tempSensorAddresses[i], scratchPad)) {
			switch (newResolution) {
			case 12:
				newValue = TEMP_12_BIT;
				break;
			case 11:
				newValue = TEMP_11_BIT;
				break;
			case 10:
				newValue = TEMP_10_BIT;
				break;
			case 9:
			default:
				newValue = TEMP_9_BIT;
				break;
			}
			// if it needs to be updated we write the new value
			if (scratchPad[CONFIGURATION] != newValue) {
				scratchPad[CONFIGURATION] = newValue;
				ds18b20_writeScratchPad((DeviceAddress*) tempSensorAddresses[i], scratchPad);
			}
			// done
			success = true;
		}
	}
	return success;
}

void ds18b20_writeScratchPad(const DeviceAddress *deviceAddress, const uint8_t *scratchPad) {
	ds18b20_reset();
	ds18b20_select(deviceAddress);
	ds18b20_write_byte(WRITESCRATCH);
	ds18b20_write_byte(scratchPad[HIGH_ALARM_TEMP]); // high alarm temp
	ds18b20_write_byte(scratchPad[LOW_ALARM_TEMP]); // low alarm temp
	ds18b20_write_byte(scratchPad[CONFIGURATION]);
	ds18b20_reset();
}

bool ds18b20_readScratchPad(const DeviceAddress *deviceAddress, uint8_t* scratchPad) {
	// send the reset command and fail fast
	int b = ds18b20_reset();
	if (b == 0) return false;
	ds18b20_select(deviceAddress);
	ds18b20_write_byte(READSCRATCH);
	// Read all registers in a simple loop
	// byte 0: temperature LSB
	// byte 1: temperature MSB
	// byte 2: high alarm temp
	// byte 3: low alarm temp
	// byte 4: DS18B20 & DS1822: configuration register
	// byte 5: internal use & crc
	// byte 6: DS18B20 & DS1822: store for crc
	// byte 7: DS18B20 & DS1822: store for crc
	// byte 8: SCRATCHPAD_CRC
	for (uint8_t i = 0; i < 9; i++) {
		scratchPad[i] = ds18b20_read_byte();
	}
	b = ds18b20_reset();
	return (b == 1);
}

void ds18b20_select(const DeviceAddress *address){
    uint8_t i;
    ds18b20_write_byte(SELECTDEVICE);           // Choose ROM
    for (i = 0; i < 8; i++) ds18b20_write_byte(((uint8_t *)address)[i]);
}

void ds18b20_requestTemperatures(){
	ds18b20_reset();
	ds18b20_write_byte(SKIPROM);
	ds18b20_write_byte(GETTEMP);
    unsigned long start = esp_timer_get_time() / 1000ULL;
    while (!isConversionComplete() && ((esp_timer_get_time() / 1000ULL) - start < millisToWaitForConversion())) vPortYield();
}

bool isConversionComplete() {
	uint8_t b = ds18b20_read();
	return (b == 1);
}

uint16_t millisToWaitForConversion() {
	switch (bitResolution) {
	case 9:
		return 94;
	case 10:
		return 188;
	case 11:
		return 375;
	default:
		return 750;
	}
}

bool ds18b20_isConnected(const DeviceAddress *deviceAddress, uint8_t *scratchPad) {
	bool b = ds18b20_readScratchPad(deviceAddress, scratchPad);
	return b && !ds18b20_isAllZeros(scratchPad) && (ds18b20_crc8(scratchPad, 8) == scratchPad[SCRATCHPAD_CRC]);
}

uint8_t ds18b20_crc8(const uint8_t *addr, uint8_t len){
	uint8_t crc = 0;
	while (len--) {
		crc = *addr++ ^ crc;  // just re-using crc as intermediate
		crc = pgm_read_byte(dscrc2x16_table + (crc & 0x0f)) ^
		pgm_read_byte(dscrc2x16_table + 16 + ((crc >> 4) & 0x0f));
	}
	return crc;
}

bool ds18b20_isAllZeros(const uint8_t * const scratchPad) {
	for (size_t i = 0; i < 9; i++) {
		if (scratchPad[i] != 0) {
			return false;
		}
	}
	return true;
}
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

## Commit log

2022-01-13 1.New option of external digital input 2.Assign default netif to wifi AP when AP mode enable 3.Fix bug of wifi connected LED
    [main.cpp]
2022-01-18 Fix bug of checking wifi get mac
    [main.cpp]
2022-01-20 1.Support blufi 2.Various wifi / eth network bug fix
    [main.cpp]
2022-01-21 1.Improve blufi coding struct 2.Add daisy chain config
2022-01-24 1.Add option of daisy chain network 2.Add option of blufi 3.More bug fix of network
    [main.cpp]
2022-06-07 Various fix for esp-idf v5.0
    [ds18b20.c, main.cpp, telnetd.c]

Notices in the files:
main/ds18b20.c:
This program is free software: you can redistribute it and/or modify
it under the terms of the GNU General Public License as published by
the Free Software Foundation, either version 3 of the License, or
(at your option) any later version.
